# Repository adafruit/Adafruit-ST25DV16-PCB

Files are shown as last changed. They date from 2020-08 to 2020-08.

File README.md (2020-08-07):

## Adafruit Adafruit ST25DV16K I2C RFID EEPROM Breakout - STEMMA QT / Qwiic PCB

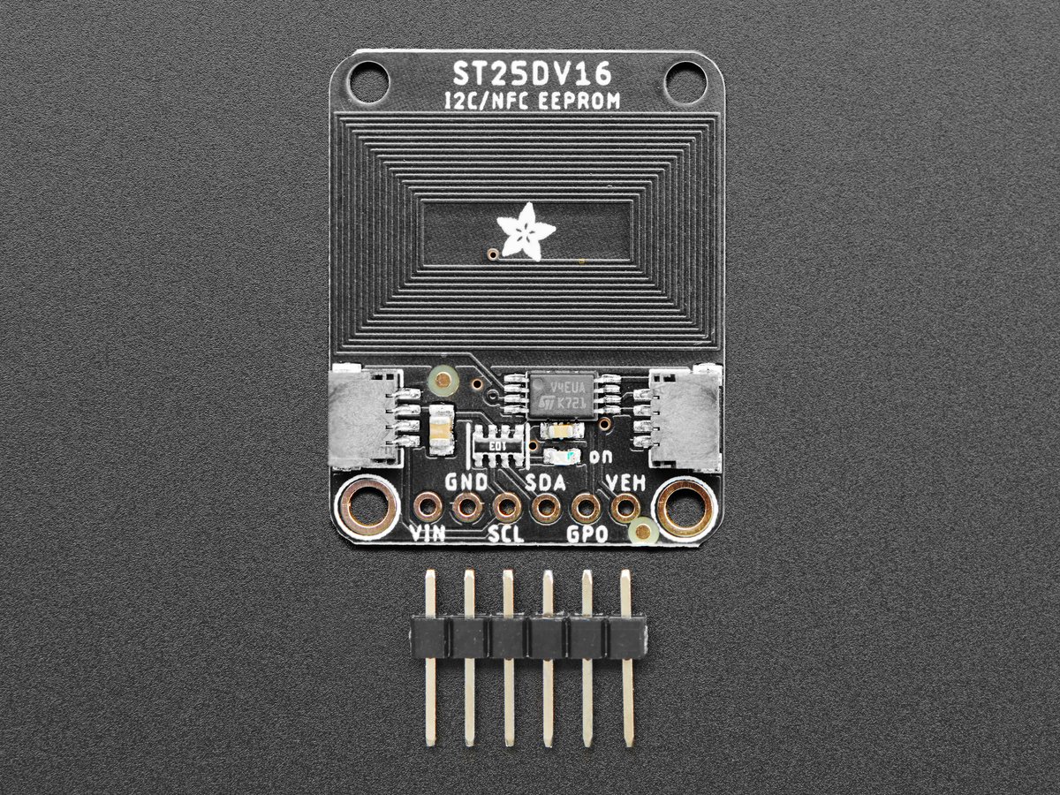
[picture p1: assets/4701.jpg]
<a href="http://www.adafruit.com/products/4701"><br/>
Click here to purchase one from the Adafruit shop</a>

PCB files for the Adafruit Adafruit ST25DV16K I2C RFID EEPROM Breakout - STEMMA QT / Qwiic. 

Format is EagleCAD schematic and board layout
* https://www.adafruit.com/product/4701

### Description

This RFID tag is really unique: it works with mobile phones just like other RFID tags, but you can reprogram it over I2C. The tag shows up as an ISO/IEC 15693 (13.56MHz) chip which is readable by phones and tablets. This could be interesting in situations where you want a  tag that can be re-written dynamically when connected to a controller. For example, we did a test where we had a microcontroller write different URLs a few seconds apart, and the mobile phone detected the different URLs one after the other.

### License

Adafruit invests time and resources providing this open source design, please support Adafruit and open-source hardware by purchasing products from [Adafruit](https://www.adafruit.com)!

Designed by Kattni Rembor for Adafruit Industries.

Creative Commons Attribution/Share-Alike, all text above must be included in any redistribution. 
See license.txt for additional details.

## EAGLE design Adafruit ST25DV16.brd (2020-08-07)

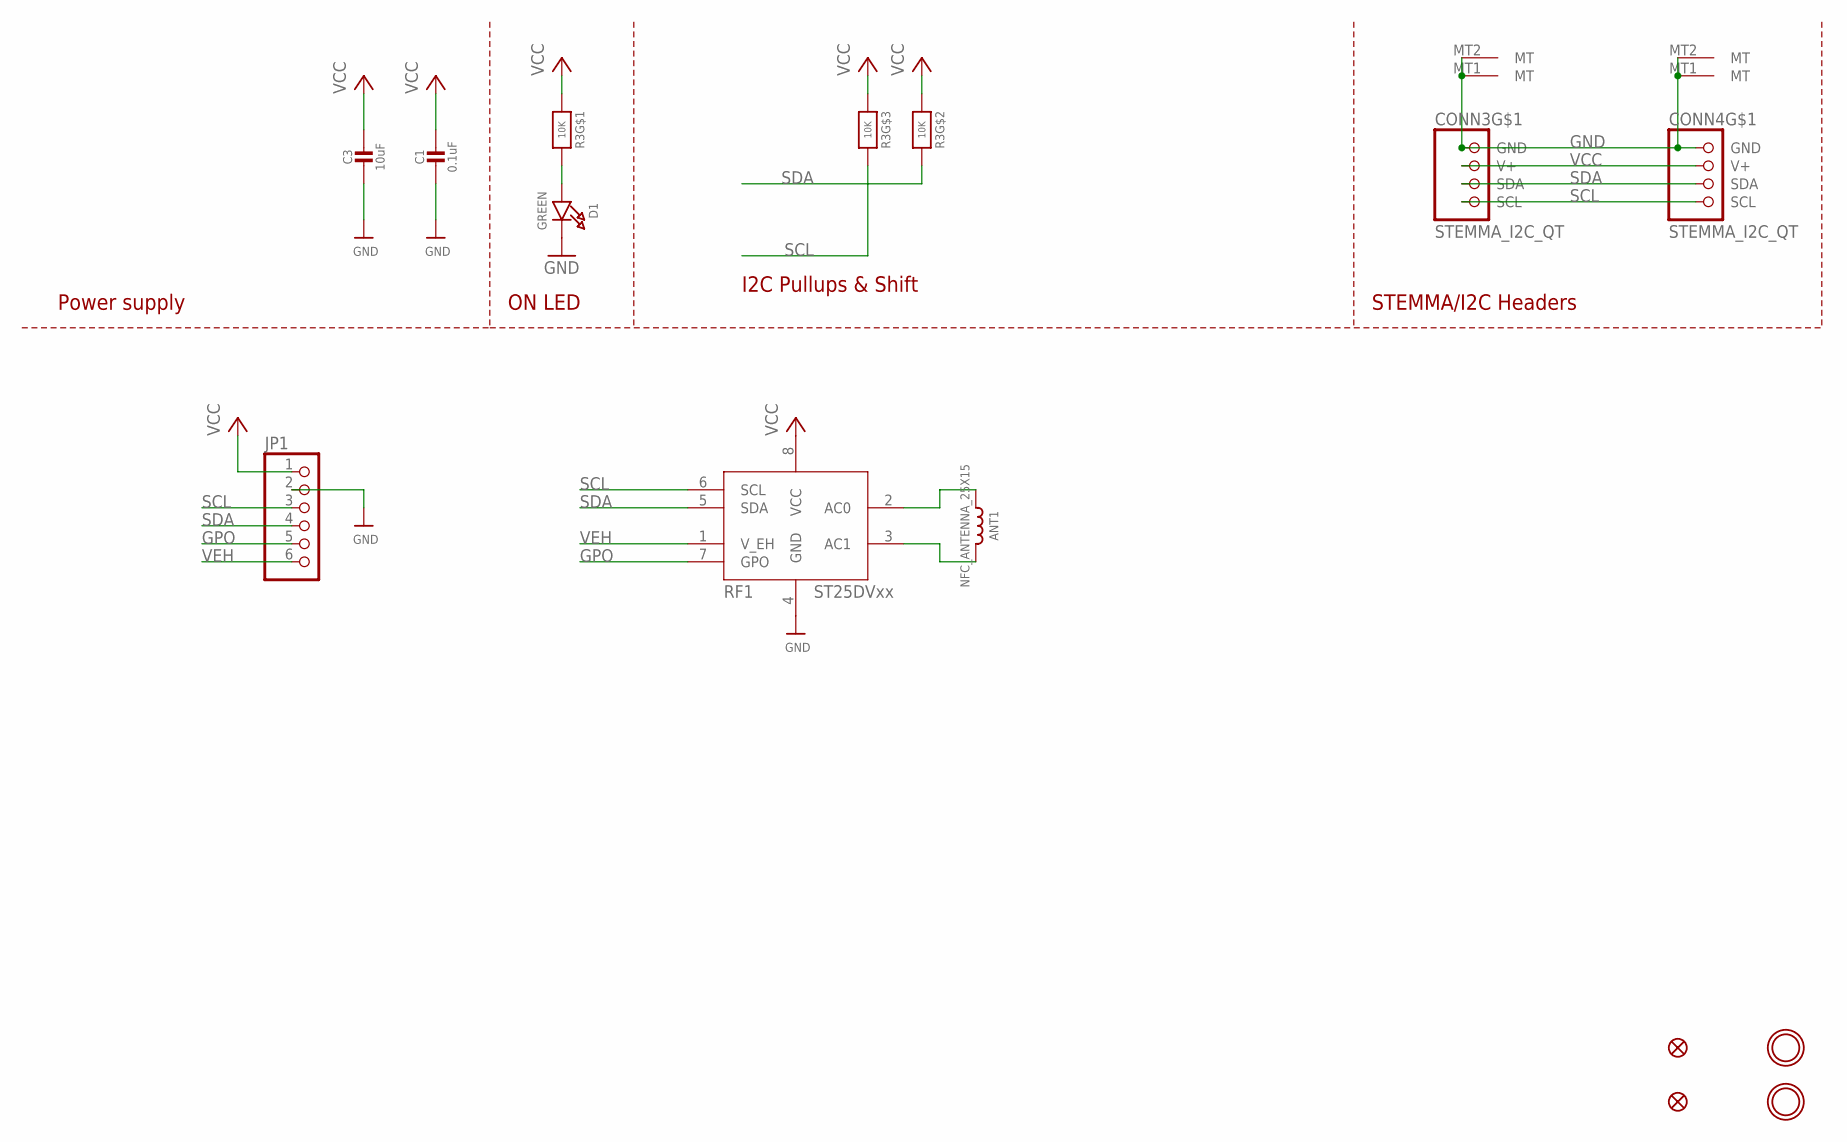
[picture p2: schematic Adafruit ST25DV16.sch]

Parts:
ANT1: NFC_ANTENNA_25X15; NFCANT_25X15
C1: 0.1uF; 0603-NO
C3: 10uF; 0805-NO
CONN3, CONN4: STEMMA_I2C_QT; JST_SH4
D1: GREEN; CHIPLED_0603_NOOUTLINE
FID3, FID4: FIDUCIAL_1MM
JP1: HEADER-1X670MIL; 1X06_ROUND_70
R3: 10K; RESPACK_4X0603
RF1: ST25DVXX_TSSOP; TSSOP8-4.4MM
U$19, U$21: MOUNTINGHOLE2.5; MOUNTINGHOLE_2.5_PLATED

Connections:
GND: C1.2, C3.2, CONN3.1 (GND), CONN3.MT1 (MT), CONN3.MT2 (MT), CONN4.1 (GND), CONN4.MT1 (MT), CONN4.MT2 (MT), D1.C, JP1.2, RF1.4 (GND)
GPO: JP1.5, RF1.7 (GPO)
unnamed: D1.A, R3.8 (2)
unnamed: ANT1.P$2 (2), RF1.2 (AC0)
unnamed: ANT1.P$1 (1), RF1.3 (AC1)
SCL: CONN3.4 (SCL), CONN4.4 (SCL), JP1.3, R3.6 (2), RF1.6 (SCL)
SDA: CONN3.3 (SDA), CONN4.3 (SDA), JP1.4, R3.7 (2), RF1.5 (SDA)
VCC: C1.1, C3.1, CONN3.2 (V+), CONN4.2 (V+), JP1.1, R3.1, R3.2 (1), R3.3 (1), RF1.8 (VCC)
VEH: JP1.6, RF1.1 (V_EH)

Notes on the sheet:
I2C Pullups & Shift
STEMMA/I2C Headers
ON LED
Power supply

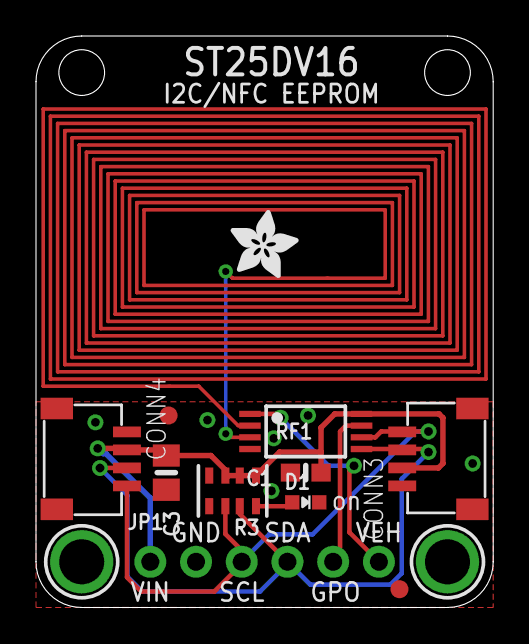
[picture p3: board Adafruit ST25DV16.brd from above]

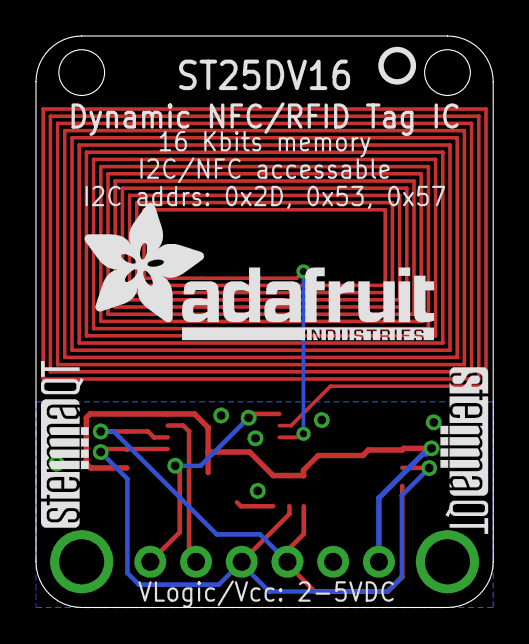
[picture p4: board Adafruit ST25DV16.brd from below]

Board: 2 copper layers, 25.4 x 31.8 mm, 18 parts (4 on the bottom side), 9 nets.

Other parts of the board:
U$1: ADAFRUIT_TEXT_20MM
U$22: ADAFRUIT_3.5MM
U$25: PCBFEAT-REV-040
U$30, U$31: STEMMAQT

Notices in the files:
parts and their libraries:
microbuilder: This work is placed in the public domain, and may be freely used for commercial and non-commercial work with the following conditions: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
